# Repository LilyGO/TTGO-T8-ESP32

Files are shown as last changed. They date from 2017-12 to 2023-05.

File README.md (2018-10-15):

# TTGO-T8-ESP32

## T8 V1.7
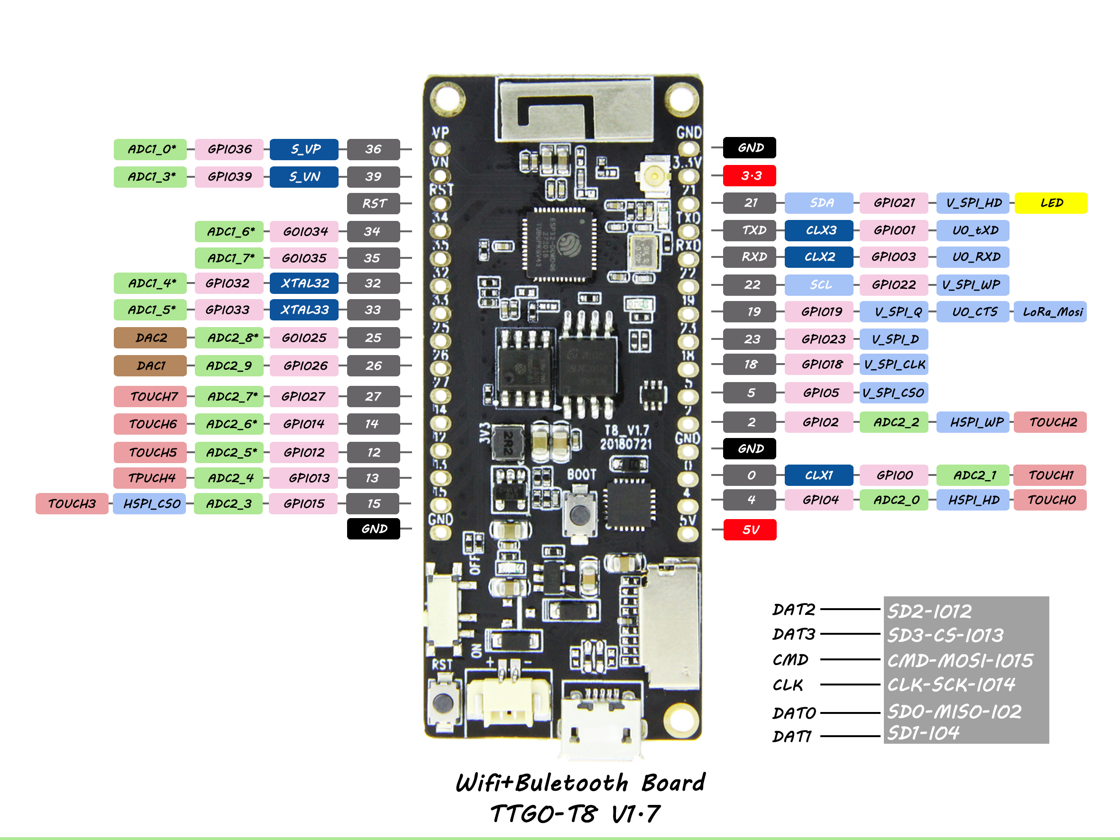
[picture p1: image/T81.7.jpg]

## T8 V1.3
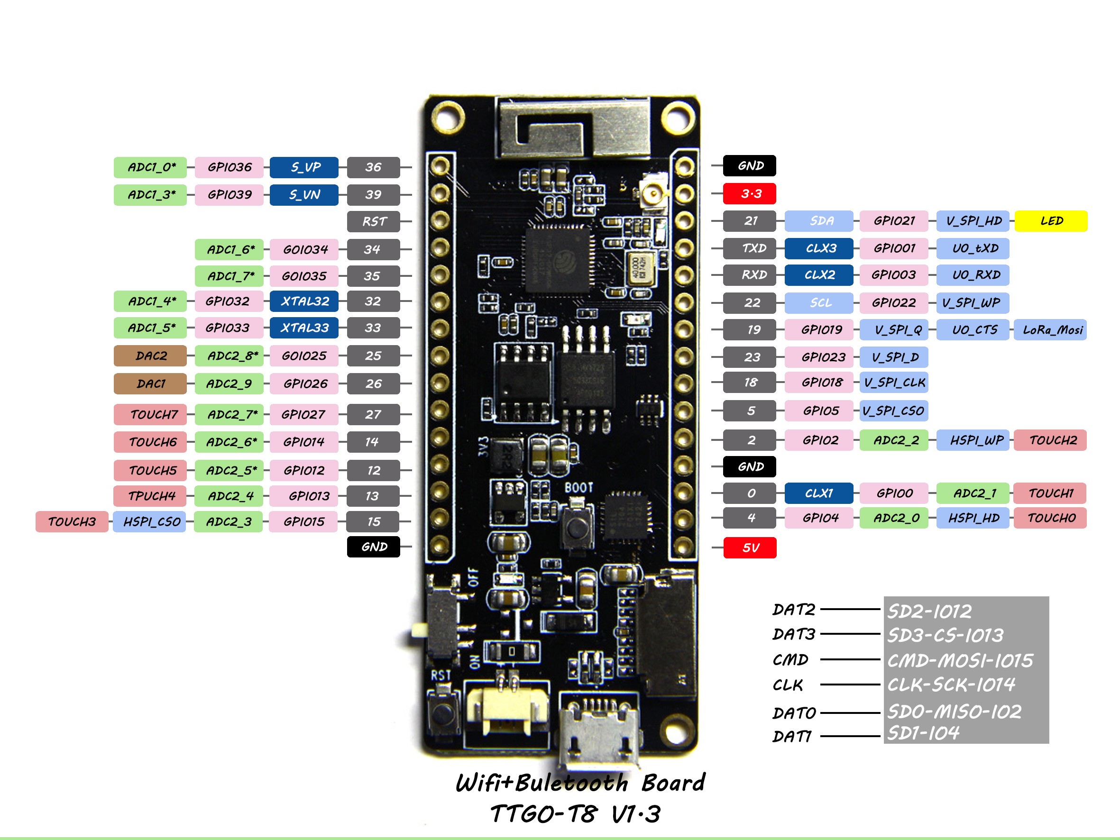
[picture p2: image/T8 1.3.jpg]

## T8 V1.1
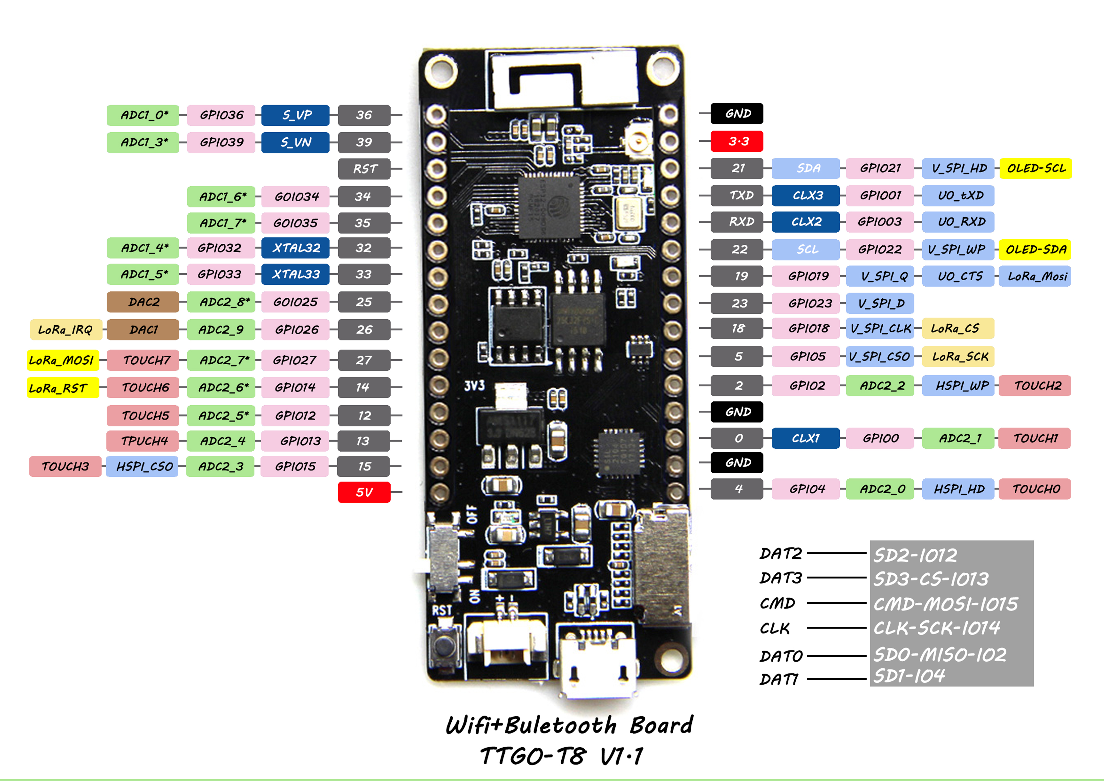
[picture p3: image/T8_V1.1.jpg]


esp32-i2s-sdcard-wav-player
Connect hardware like below:

[ESP32 IO33 – CS MICROSD]

[ESP32 IO14 – MOSI MICROSD]

[ESP32 IO12 – MISO MICROSD]

[ESP32 IO27 – SCK MICROSD]

[ESP32 IO26 – I2S codec BCK]

[ESP32 IO22 – I2S codec DATA]

[ESP32 IO25 – I2S codec LRCK]

[ESP32 GND – I2S codec GND]

[ESP32 GND – GND MICROSD]

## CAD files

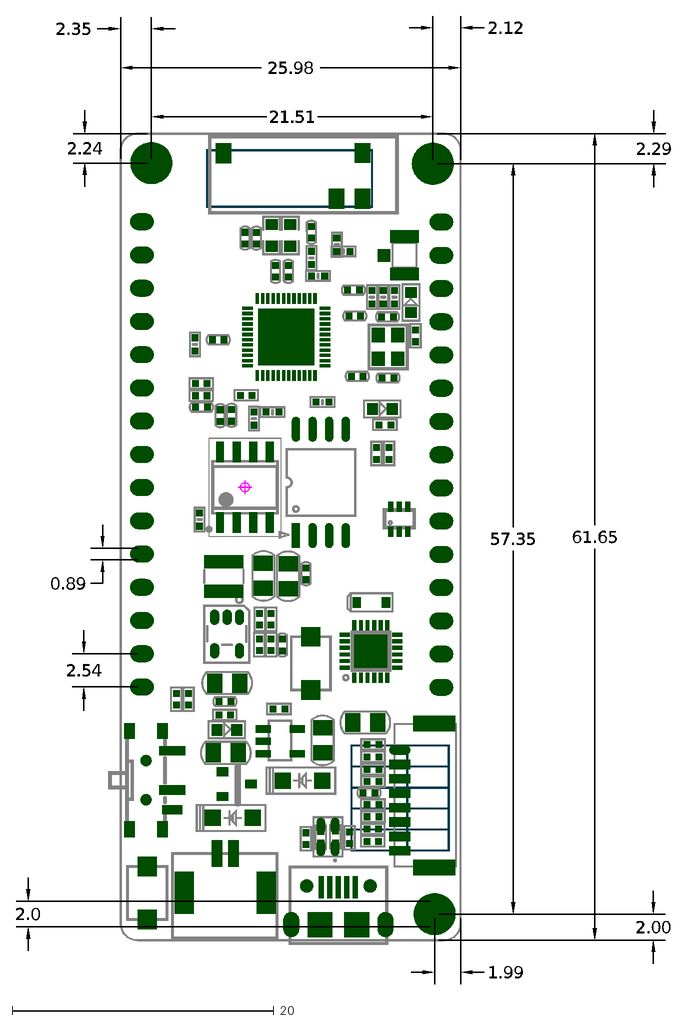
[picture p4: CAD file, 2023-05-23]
T8_V1.7.dxf
21.51
25.98
57.35
61.65
2.54
0.89
1.99
2.24
2.00
2.29
2.12
2.35
2.0

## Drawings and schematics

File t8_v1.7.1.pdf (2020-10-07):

5V-3.3V

## VBUS-VBAT-VIN

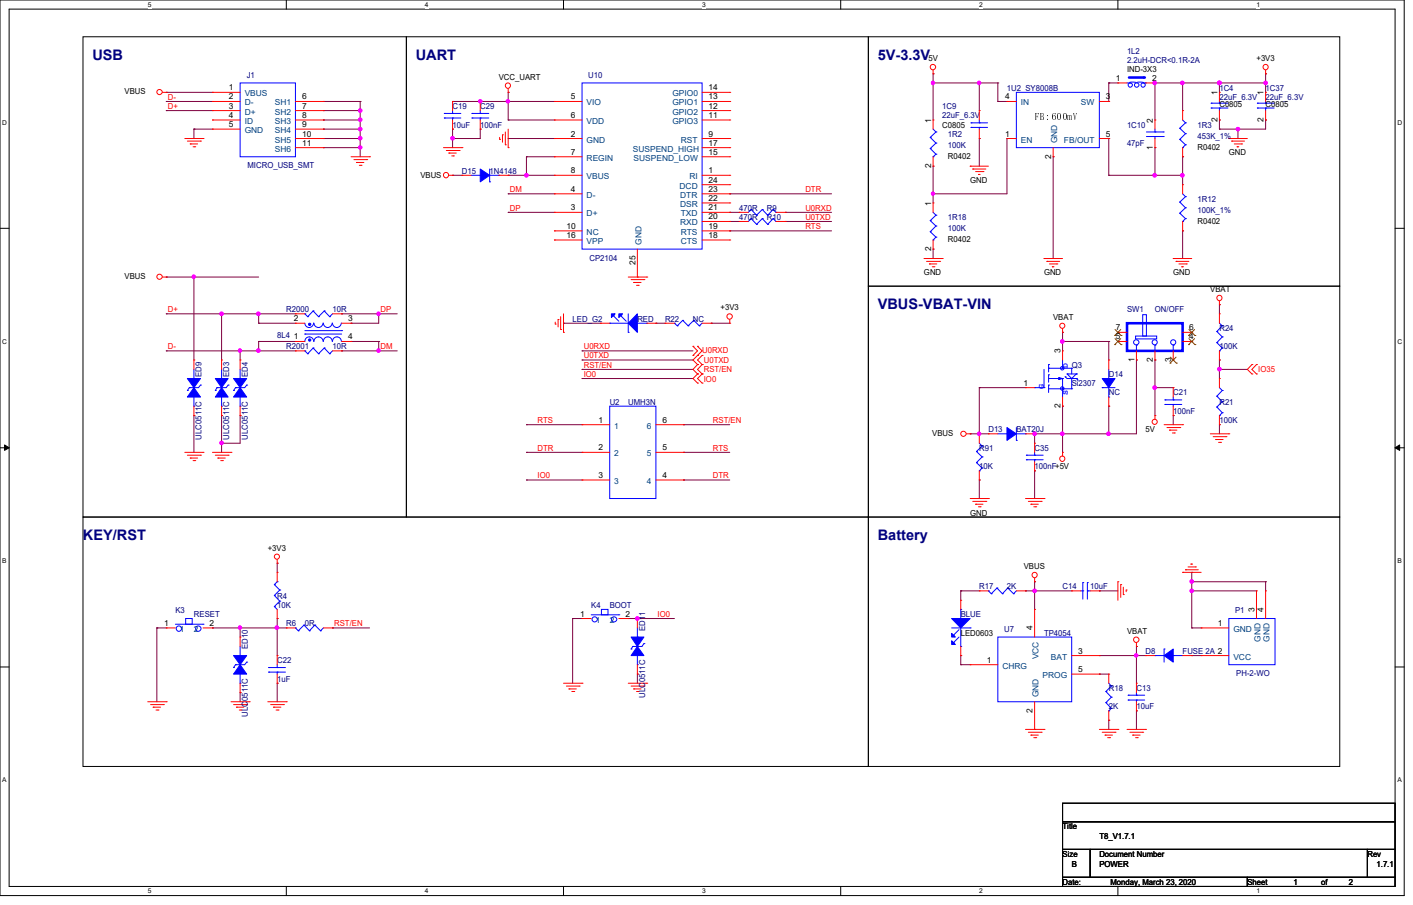
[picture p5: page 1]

## ESP32 Module:with 1.8V Flash & SRAM

The operating voltage for signals marked in blue is 1.8V.

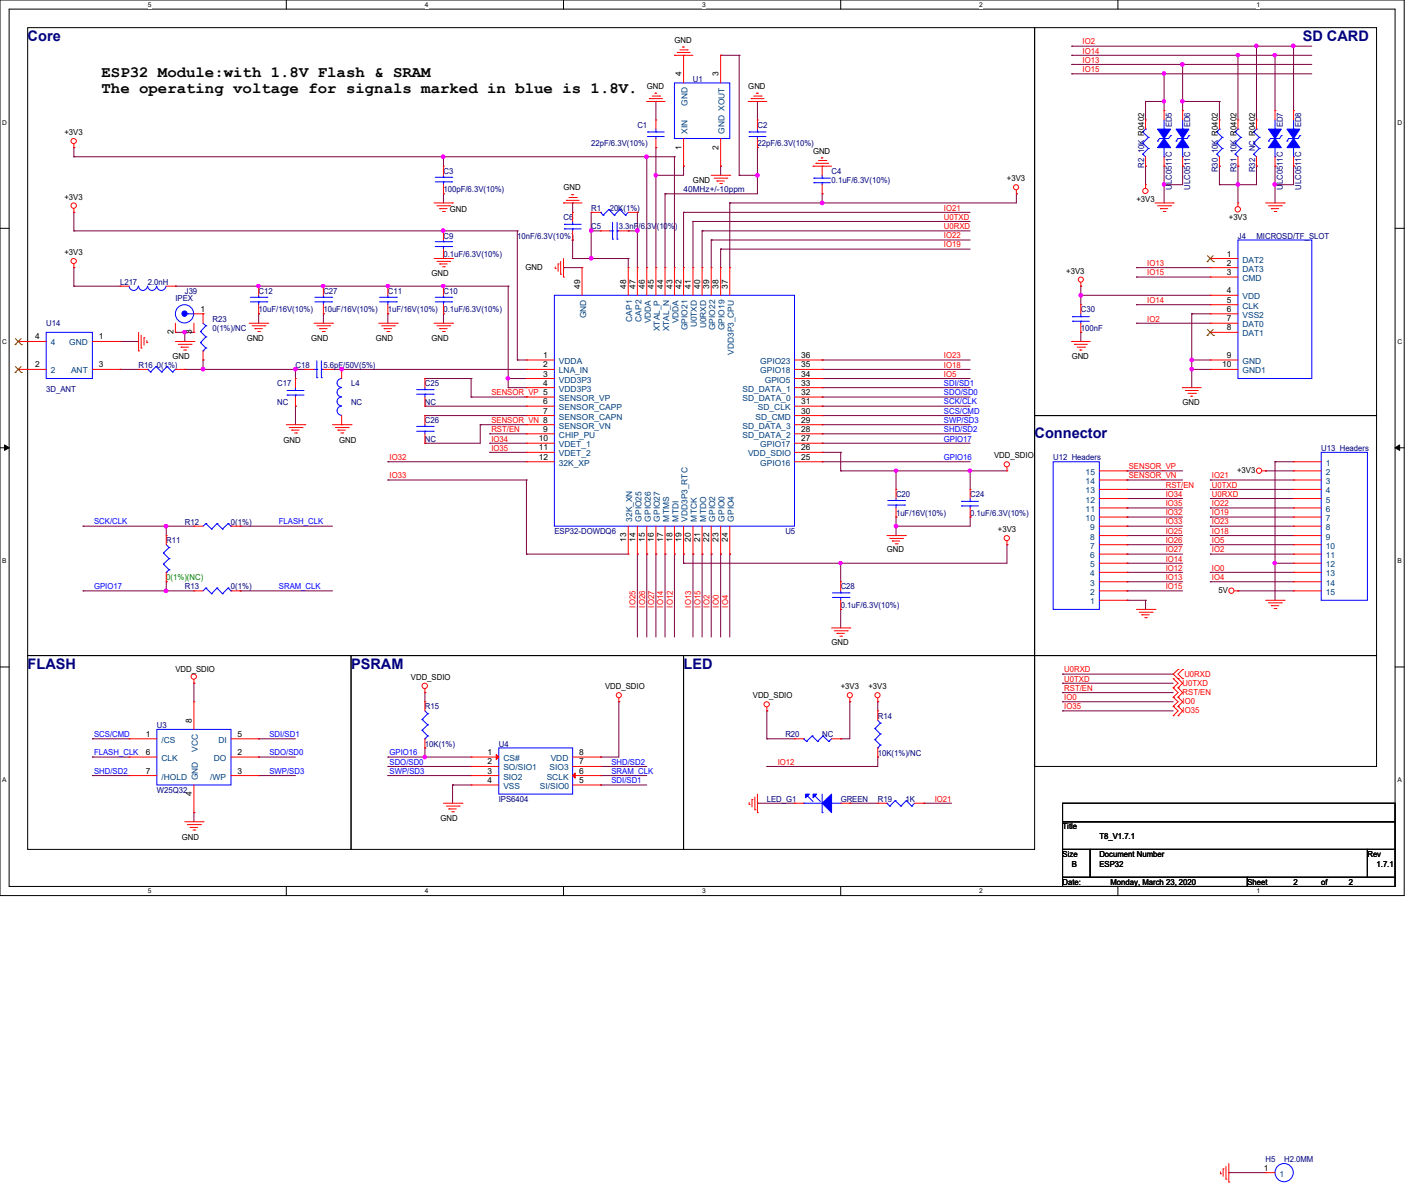
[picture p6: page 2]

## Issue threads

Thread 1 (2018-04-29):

On-board LEDs

elf55, 2018-04-29:
There are at least 3 on-board LEDs.  Is there documentation on how they are connected to GPIO pins?

LilyGO, 2018-05-24:
One is a power light, and the other is an LED foot controlled by the GPIO21 pin.

LilyGO, 2018-05-24:
If you need it, we can send you a T8 schematic

amirgon, 2018-05-24:
What would happen to the power light during deep-sleep? Would it still be on?

elf55, 2018-05-24:
A schematic would solve all questions, but knowing what the LEDs are connected to helps immediately.

pilnikov, 2018-08-14:
I need a schematic too
gpio 16, 17 where?

remedix, 2021-01-20:
Can you please explain how to turn off these LEDs ? There is one blinking LED and one constant on LED

pilnikov, 2021-01-21:
just unsolder

johndoesenior, 2021-02-04:
I need the schematic also.
I cant find TX2,RX2 in the pinout

Closed 2018-05-24.

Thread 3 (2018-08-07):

red/blue LEDs

carstenblt, 2018-08-07:
Hi there,
there are two LEDs on the board that I find are not connected to any GPIO. Am I just missing the right one? Any way to disable them via software?

Thanks in advance.

wieb18, 2019-02-03:
There is only 2 LEDs on this board, BLUE (power indicator) and GREEN (wifi indicator).
The GREEN LED can be controlled with GPIO21.
To turn off the BLUE LED, power the board through Lithium battery interface.

heeen, 2019-05-09:
the blue LED is connected to the battery charging controller, it goes off if the battery is not charging
the red LED is supposed to light when the board is powered, but it is not working for me, neither from USB, nor from a battery

heeen, 2019-05-09:
@LilyGO is it a known issue that the red led is not working?

PureBasic, 2019-05-10:
Wait, there is a red led ?
Doesn't work on my board neither then.

Le jeu. 9 mai 2019 à 19:30, Florian Hänel <notifications@github.com> a
écrit :

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

PureBasic, 2019-05-10:
Okay, just looked at it closely, the red led (LED_G2) is implanted but R22 (the 1k brake) is not.
If you want the red led to work you will need to solder the 0402 resistor. I believe they didn't implanted it to avoid draining batteries continuously. Better to blink LED_G1 (IO21) when needed

stanleyseow, 2020-05-19:
Where did you find the schematics for TTGO T18 V3.0 ???

PureBasic, 2020-05-19:
What is the T18?

patrickelectric, 2023-04-20:
My RED led is blinking like crazy, how do I control it ?

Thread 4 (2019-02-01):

SOLVED: TTGO T8 SD Card CS Pin???

wieb18, 2019-02-01:
I just bought TTGO T8 V1.1 board.

The board comes with installed "Hello World" and SD Card initialization sketch. It prints "Hello World" text and shows SD card files list in Serial Monitor when turn on for the first time. So, the SD card works fine.

**The problem is now I can't make SD card works anymore.**

[https://ae01.alicdn.com/kf/HTB1laFLXinrK1Rjy1Xcq6yeDVXaf.jpg](url)

Board picture says the SD card CS Pin is GPIO 13 but doesn't work. Already tried changing CS pin to GPIO 2, 4, 14, 15 but also doesn't work.

```
#include <SPI.h>
#include <SD.h>

File root;

void setup() {
  // Open serial communications and wait for port to open:
  Serial.begin(115200);
  while (!Serial) {
    ; // wait for serial port to connect. Needed for native USB port only
  }

  Serial.print("Initializing SD card...");

  if (!SD.begin(13)) {
    Serial.println("initialization failed!");
    while (1);
  }
  Serial.println("initialization done.");

  root = SD.open("/");

  printDirectory(root, 0);

  Serial.println("done!");
}

void loop() {
  // nothing happens after setup finishes.
}

void printDirectory(File dir, int numTabs) {
  while (true) {

    File entry =  dir.openNextFile();
    if (! entry) {
      // no more files
      break;
    }
    for (uint8_t i = 0; i < numTabs; i++) {
      Serial.print('\t');
    }
    Serial.print(entry.name());
    if (entry.isDirectory()) {
      Serial.println("/");
      printDirectory(entry, numTabs + 1);
    } else {
      // files have sizes, directories do not
      Serial.print("\t\t");
      Serial.println(entry.size(), DEC);
    }
    entry.close();
  }
}

```
Anybody knows how to enable TTGO T8 SD card?

Thanks.

wieb18, 2019-02-02:
Finally.... it works....  :

Change _SD.h_ library with _mySD.h_ library from [https://github.com/nhatuan84/esp32-micro-sdcard](https://github.com/nhatuan84/esp32-micro-sdcard).

```
#include <SPI.h>
#include <mySD.h>

File root;
const int chipSelect = 13;

void setup()
{
  Serial.begin(115200);
  Serial.print("Initializing SD card...");
  pinMode(SS, OUTPUT);

  //SDClass::begin(uint8_t csPin, int8_t mosi, int8_t miso, int8_t sck)
  if (!SD.begin(13, 15, 2, 14)) {
    Serial.println("initialization failed!");
    return;
  }

  Serial.println("initialization done.");

  root = SD.open("/");

  printDirectory(root, 0);

  Serial.println("done!");
}

void loop()
{
  // nothing happens after setup finishes.
}

void printDirectory(File dir, int numTabs) {
  // Begin at the start of the directory
  dir.rewindDirectory();

  while(true) {
     File entry =  dir.openNextFile();
     if (! entry) {
       // no more files
       //Serial.println("**nomorefiles**");
       break;
     }
     for (uint8_t i=0; i<numTabs; i++) {
       Serial.print('\t');   // we'll have a nice indentation
     }
     // Print the 8.3 name
     Serial.print(entry.name());
     // Recurse for directories, otherwise print the file size
     if (entry.isDirectory()) {
       Serial.println("/");
       printDirectory(entry, numTabs+1);
     } else {
       // files have sizes, directories do not
       Serial.print("\t\t");
       Serial.println(entry.size(), DEC);
     }
     entry.close();
   }
}
```

Conclusion, nothing wrong with SD Card GPIO print on the back of the board.

The root of this issue cause by SD.h library which unable to detect TTGO SD card because it used custom CS, MOSI, MISO, SCK sequence.

gandy92, 2022-08-07:
It also works with the standard SD library:
```
#include <SPI.h>
#include <SD.h>

#define SD_CS 13

void setup()
{
    SPI.begin(14, 2, 15, 13);
    Serial.begin(115200);
    SD.begin(SD_CS);
    if (!SD.begin(SD_CS)) {
        Serial.println("Card Mount Failed");
        return;
    }
    uint8_t cardType = SD.cardType();
    if (cardType == CARD_NONE) {
        Serial.println("No SD card attached");
        return;
    }
    Serial.println("Initializing SD card...");
    if (!SD.begin(SD_CS)) {
        Serial.println("ERROR - SD card initialization failed!");
        return;    // init failed
    }
}
```

Closed 2019-02-02.

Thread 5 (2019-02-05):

Schematic

rochba, 2019-02-05:
Hello,
I'm working with these cards and I have a lot of questions about battery management, leds connectivity, antenna …
Is it possible to have access to the schematic. That will solve my issue.
Thanks,
Best regards,

ThomasChr, 2019-05-07:
This is the shematic: https://github.com/LilyGO/TTGO-T8-ESP32/blob/master/Schematic.pdf

Maslenikoff73, 2021-01-30:
> This is the shematic: https://github.com/LilyGO/TTGO-T8-ESP32/blob/master/Schematic.pdf
link not work :(

ThomasChr, 2021-01-30:
Try this one: https://github.com/LilyGO/TTGO-T8-ESP32/raw/master/t8_v1.7.1.pdf

Maslenikoff73, 2021-02-03:
Thanks 👍

Cyb3r-N1nja, 2022-02-28:
Does anyone here have a working source code to display something to the Display because in my case it says written successfully and the screen remains black

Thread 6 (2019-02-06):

Which board should i use?

sync5, 2019-02-06:
I'm not sure which esp32 board from the Arduino IDE should I use for this ttgo-t8 1.3? Thanks.

knopserl, 2019-03-17:
same question here: TTGO T8 v1.7. it would be nice and required if a board definition is provided for Arduino Studio.
We always have o use another board like WEMOS LOLIN32 and do a lot of manual works to redefine and add the additional peripherals like the SD Cards etc.

m-menon, 2019-04-11:
> I'm not sure which esp32 board from the Arduino IDE should I use for this ttgo-t8 1.3? Thanks.

LOLIN D32 PRO seems to work for me. I had my board running only for a short while so I haven't tested it completely. The only thing I tested was a I2C OLED on pins 21/22 (SDA/SCL).

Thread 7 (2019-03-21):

microSD data pins

kaofishy, 2019-03-21:
The pinout for all versions of the board states that the microSD data pins are correctly connected to the SDMMC host interface on the ESP32, but in the schematics it shows DAT1-3 as disconnected and only DAT0 connected. On the board I have I can only make SDMMC work in 1-bit mode so it suggests to me the schematics is correct. Please confirm whether this is the case or not. Thanks.

tionebrr, 2020-07-22:
The sd slot is wired in SPI 1-bit mode.

venice1200, 2021-03-20:
I can confirm working 1-Bit SD-Bus-Mode and SPI Mode.
But I have to **SD_MMC.begin("/sdcard", true)** twice in my Arduino Sketch.
First **.begin** fails, second is OK.

koradeh, 2024-06-01:
`// pullup GPIO2 for SD_MMC mode, you need 1-15kOm resistor connected to GPIO2 and GPIO19 `
Or
`pinMode(2, INPUT_PULLUP);`

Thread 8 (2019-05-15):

Deepsleep only 3.5 mA

ThomasChr, 2019-05-15:
When I put the ESP32 in deepsleep I still have a power draw of ~3.5mA.
Can you explain why is that so, and can I do anything about it?

ThomasChr, 2019-05-17:
I‘ve desoldered the SIL2104 and now the power consumption is down to 3.1 mA, better, but far from the uA the ESP32 is capable of!

ThomasChr, 2019-05-20:
The problems seems to be that VDD_SDIO stays at 3.3V in deepsleep, so flash and psram do not get powered down.

ThomasChr, 2019-05-20:
Some news here:
1. VDD_SDIO does not go low when entering deepsleep. It seems that the Resistor R20 is placed on the board and pulling VDD_SDIO to 3.3V. Removing it helped and I lost one more mA (1.5 mA total in deepsleep)
2. I powered the board directly on the 3.3V rail, so the SYS8008B Voltage regulator was not involved and I'm down to 295 µA.

So still there are some 280 µA to catch. Anyone got an idea what I can try now?
Of course, everything is allowed, even experiments which will destroy the board, all to satisfy my curiosity!

ThomasChr, 2019-05-21:
After blowing the power IC completely from the board the power consumption is down to 100 µA - getting there! Any hints what should be blown off next? Some pullup resistors maybe?

PureBasic, 2019-05-21:
Wow, that was a very leaky regulator...
You could just check the voltage across all the remaining resistors. R1, R4, R11, R12, R13, R14 and R19. Also there is 1R3 and 1R12 voltage divider close to the SYS8008B if still connected draining a bit for sure.
It may also be a leaky cap somewhere, which is harder to find.

ThomasChr, 2019-05-21:
Hi PureBasic, thank you very much for your answer!

Is there anywhere a Layout of the board? The resistors are not marked on the PCB which makes it very hard to find the right one!

PureBasic, 2019-05-22:
Arf you will have to follow the schematic, count the pins and so on... There is no TOPCOMP sheet from what I gathered.
1R3 and 1R12 should be close the SYS8008, they are draining 6uA (553k @ 3.3v).

How much exceding current do you still have to find ? You are feeding power directly to the 3v3 net or VBat ?

ThomasChr, 2019-05-22:
Hello PureBasic,

I just blowed some resistors of the board and this is the outcome:
1. Without voltage regulator (providing 3.3V directly on the rail): 100 µA
2. Without the Voltage Divider from the Power IC: 90 µA
3. Without the pullups for the SD Card IO Lines: 5 µA

So I think I'm pretty much done :-)

PureBasic, 2019-05-22:
Nice !
It's weird that the SD pullups are draining that much current, because they are marked as NC on the schematic, so maybe you actually removed the ESD protections 😆.
Did you checked the state of the IOs of the ESP32 when it goes in hibernation ? They should all be put in "INPUT" mode with no internal pullups or pulldowns, so virtually connected to nothing inside the ESP32.

Civilduino, 2019-07-22:
And NC means Not Connected?

PureBasic, 2019-07-22:
Yes. But check on the board, you never know...

hpsaturn, 2020-04-14:
Nice thread, guys maybe you know what is the better TTGO board "out the box" with this improvements? thats is, what board has the better performance for hibernation without any hack?
For example TTGO-T-Writsband in my tests reached ~3 days only on suspend mode (not bad because the battery is very tiny), maybe the TTGO T-Display will be? (I'm waiting for a one board for starting tests)

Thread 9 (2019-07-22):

External antenna TTGO T8

Civilduino, 2019-07-22:
I got the TTGO T8 V1.7 20180721 and I will like to use the external antenna connector. Is it just to plug the antenna?

I tried that I don't think it is working. Do I need to solder some resistor, cut a trace? add a jumper?

Without the antenna the board is useless for my application.

Thank you for clarification and improving the documentation. Some pictures of what to do should be good.

KuhlTime, 2020-06-27:
I am having the same question. Looking at the schematic I would assume that you have to desolder R16 and bridge R23 (or use the desoldered 0Ω resistor). It would be nice to get some clarification on this though.

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

vaughnlfisher, 2021-03-26:
Did you ever get an answer to this

LiveRock, 2021-07-02:
Any answer to this? I bridge R23 with a wire (not resistor) and the performance because much much worse even with an external antenna...

KuhlTime, 2021-07-04:
Sadly I did not get an answer. My performance decreased as well when I tried that.

KuhlTime, 2021-07-04:
Maybe good to point out that there is another question regarding the IPEX antenna: https://github.com/LilyGO/TTGO-T8-ESP32/issues/20

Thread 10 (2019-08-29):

TTGO T8 V1.7 cannot be powered on from the battery

dukeduck1984, 2019-08-29:
Hi,

I recently bought 2 TTGO T8 V1.7 boards, neither can be powered on from a 18650 battery (fully charged, voltage measured 4.3V).  I also have a T8 V1.3 which works properly with the very same battery.

Any idea what can go wrong?

Thanks.

mattsmithuk, 2025-01-18:
Can I ask what the issue was? I am having a similar issue

Closed 2019-09-06.

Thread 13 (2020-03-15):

Battery measurement

eried, 2020-03-15:
Hi!

I just wanted to add that it would be useful to have the following info in the repo:

1) PIN 35 measures the VBAT (or USB) with a resistor divider bundled in the board.

```
    #define PIN_VBAT 35
    int v = analogRead(PIN_VBAT); // This returns the battery level
```

2) VCC does not provide any power if we use the battery (I do not know why, but it would be useful to change this in the pcb for next revision and provide USB/VBAT)

paolovr70, 2020-03-26:
Eried I have T8 1.7.1 board. Analog read finds a value in PIN35 around 2430. This level is present both with BATTERY connected and also with NO BATTERY. Are you sure that it correspond to V.bat?

eried, 2020-03-26:
Yes, in that case is USB voltage

paolovr70, 2020-03-27:
But what is the scale of 0-4095.measurement? Because lithium battery is 3.0-4.2v. Board and pins volt are maximum 3.3v and 0-4095 usually are for 0-3.3v. How.did you manage that?

eried, 2020-03-27:
Well, I didnt exactly needed the voltage value, just the reference (because the analogRead changes for every input responding to VBAT, so the values are all different if you are on battery power vs USB)

So what I did is to map the range:
https://github.com/eried/pidflight-lap-firmware/blob/master/pidflight_lap/rx5808.ino#L37

For a simple mapping I would use:

    #define PIN_VBAT 35
    double v = analogRead(PIN_VBAT)  / 4096 / 2 / 4.2 ; // This returns the voltage (max range / voltage divider / max battery voltage )
    // voltage divider = in the PCB of the T8 you can see there is 2 equal resistors, hence 50% division
    // max battery voltage = this is the output of the lipo charging circuitry before it gets to the 3.3 regulator... this circuit is before the ON/OFFswitch)

For a more accurate reading, I would calibrate a mapping with few known voltages and an polinomial interpolation in excel.

eried, 2020-03-27:
Also, consider that while reading the serial monitor via USB you will always get the same VBAT. Create a sketch with a simple bluetooth serial and try with different batteries.

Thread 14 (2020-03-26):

LEDS on TTGO ESP32 T8 1.7.1

paolovr70, 2020-03-26:
Dear All,
where can I find a pinout of the board? (on the site producer there is no schematic).
There are 3 leds on board. One is for battery, but the other two?
Are there problems if I need to use I2C and one of the leds is connected to 21/22 pins (which are the hardware I2C pins)?
Thanks.
paolo

tionebrr, 2020-07-22:
I Paolo.
- According to the schematic, blue is for battery charge, red is the 3v3 power, and green is wired to IO21.
- Schematic is in this repository, but the version changes are not pushed here. The pinout is the same as other official ESP32 modules.
- You can use any pin as I²C with the ESP32. GPIOs are actually very flexible. Refer to the ESP32 datasheet.

There is not a lot of help or information about this specific module (the T8) because there is nothing special about it really. It is wired like most other ESP32 modules and thus can be used like any other module. Only difference is the SDCard slot which is actually wired in SPI mode like shown on the schematic and not like advertised.

hasaranga, 2021-01-21:
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

Can it run in 1bit mode? Because I have the same board but the first call to **SD_MMC.begin("/sdcard", true)** always fail. Second call works. Tried with a different SD card and reduced the cpu freq but the same results.

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

tionebrr, 2021-01-22:
I'm using the ESP-IDF and thus don't know anything about the specifics of the arduino implementation.
Remember, the SDCard is wired as an SPI device, so it is one bit. There might be a way to tell SD_MMC to initialize as an SPI SD.

dizcza, 2021-09-03:
@tionebrr could you please clarify this

> Remember, the SDCard is wired as an SPI device, so it is one bit

aren't you trying to say that an SD card will work only in 1-bit width mode for this board while using the SD-MMC driver?

tionebrr, 2021-09-03:
@dizcza Good question.
The SDCard socket is not wired on SDMMC pins. So you can't have a 1-bit SDMMC.
I used the [SDSPI Host Driver](https://docs.espressif.com/projects/esp-idf/en/latest/esp32/api-reference/peripherals/sdspi_host.html) to make it work.

tionebrr, 2021-09-03:
@dizcza You're right, sorry for the confusion. I re-checked the docs and it should work in SDMMC 1-bit mode. I edited my previous comment.

dizcza, 2021-09-03:
@tionebrr thank you for the clarification. It did help because I thought I was doing something wrong by not being able to mount an SD card with the 4-bit operation mode.

BTW, shouldn't this issue be closed? It has been answered fairly in the first comment. The author perhaps was wondering whether the LED will be blinking if IO21 pin is used as SDA with some I2C-connected device. In either case, you can't use it as LED with active I2C communication going through this pin.

Let me also answer another question posted here to quantify it's fully resolved.
@hasaranga you had the following problem:
> ... I have the same board but the first call to SD_MMC.begin("/sdcard", true) always fail. Second call works.

It's because a pull-up resistor is missing on D0 line (as in many other variants of an ESP32 board). You can do either a hardware fix (pulling up a 10 kOhm resistor to pin "2") or a software fix. The software fix is to call `pinMode(2, INPUT_PULLUP);` prior to initializing the SD card. Below is a working example of using SDMMC driver with TTGO T8 in Arduino IDE with the latest esp32 library installed (v1.0.6; I've not checked v2.0.0 yet).

<details>
    <summary>An example of using SDMMC driver with TTGO T8 in Arduino IDE</summary>

```c
/*
 * Connect the SD card to the following pins:
 *
 * SD Card | ESP32
 *    D2       12
 *    D3       13
 *    CMD      15
 *    VSS      GND
 *    VDD      3.3V
 *    CLK      14
 *    VSS      GND
 *    D0       2  (add 1K pull up after flashing)
 *    D1       4
 */

#include "FS.h"
#include "SD_MMC.h"

void listDir(fs::FS &fs, const char * dirname, uint8_t levels){
    Serial.printf("Listing directory: %s\n", dirname);

    File root = fs.open(dirname);
    if(!root){
        Serial.println("Failed to open directory");
        return;
    }
    if(!root.isDirectory()){
        Serial.println("Not a directory");
        return;
    }

    File file = root.openNextFile();
    while(file){
        if(file.isDirectory()){
            Serial.print("  DIR : ");
            Serial.println(file.name());
            if(levels){
                listDir(fs, file.name(), levels -1);
            }
        } else {
            Serial.print("  FILE: ");
            Serial.print(file.name());
            Serial.print("  SIZE: ");
            Serial.println(file.size());
        }
        file = root.openNextFile();
    }
}

void createDir(fs::FS &fs, const char * path){
    Serial.printf("Creating Dir: %s\n", path);
    if(fs.mkdir(path)){
        Serial.println("Dir created");
    } else {
        Serial.println("mkdir failed");
    }
}

void removeDir(fs::FS &fs, const char * path){
    Serial.printf("Removing Dir: %s\n", path);
    if(fs.rmdir(path)){
        Serial.println("Dir removed");
    } else {
        Serial.println("rmdir failed");
    }
}

void readFile(fs::FS &fs, const char * path){
    Serial.printf("Reading file: %s\n", path);

    File file = fs.open(path);
    if(!file){
        Serial.println("Failed to open file for reading");
        return;
    }

    Serial.print("Read from file: ");
    while(file.available()){
        Serial.write(file.read());
    }
}

void writeFile(fs::FS &fs, const char * path, const char * message){
    Serial.printf("Writing file: %s\n", path);

    File file = fs.open(path, FILE_WRITE);
    if(!file){
        Serial.println("Failed to open file for writing");
        return;
    }
    if(file.print(message)){
        Serial.println("File written");
    } else {
        Serial.println("Write failed");
    }
}

void appendFile(fs::FS &fs, const char * path, const char * message){
    Serial.printf("Appending to file: %s\n", path);

    File file = fs.open(path, FILE_APPEND);
    if(!file){
        Serial.println("Failed to open file for appending");
        return;
    }
    if(file.print(message)){
        Serial.println("Message appended");
    } else {
        Serial.println("Append failed");
    }
}

void renameFile(fs::FS &fs, const char * path1, const char * path2){
    Serial.printf("Renaming file %s to %s\n", path1, path2);
    if (fs.rename(path1, path2)) {
        Serial.println("File renamed");
    } else {
        Serial.println("Rename failed");
    }
}

void deleteFile(fs::FS &fs, const char * path){
    Serial.printf("Deleting file: %s\n", path);
    if(fs.remove(path)){
        Serial.println("File deleted");
    } else {
        Serial.println("Delete failed");
    }
}

void testFileIO(fs::FS &fs, const char * path){
    File file = fs.open(path);
    static uint8_t buf[512];
    size_t len = 0;
    uint32_t start = millis();
    uint32_t end = start;
    if(file){
        len = file.size();
        size_t flen = len;
        start = millis();
        while(len){
            size_t toRead = len;
            if(toRead > 512){
                toRead = 512;
            }
            file.read(buf, toRead);
            len -= toRead;
        }
        end = millis() - start;
        Serial.printf("%u bytes read for %u ms\n", flen, end);
        file.close();
    } else {
        Serial.println("Failed to open file for reading");
    }

    file = fs.open(path, FILE_WRITE);
    if(!file){
        Serial.println("Failed to open file for writing");
        return;
    }

    size_t i;
    start = millis();
    for(i=0; i<2048; i++){
        file.write(buf, 512);
    }
    end = millis() - start;
    Serial.printf("%u bytes written for %u ms\n", 2048 * 512, end);
    file.close();
}

void setup(){
    Serial.begin(115200);
    delay(1000);
    pinMode(2, INPUT_PULLUP);
    if(!SD_MMC.begin("/sdcard", true, false)){
        Serial.println("Card Mount Failed");
        return;
    }
    uint8_t cardType = SD_MMC.cardType();

    if(cardType == CARD_NONE){
        Serial.println("No SD_MMC card attached");
        return;
    }

    Serial.print("SD_MMC Card Type: ");
    if(cardType == CARD_MMC){
        Serial.println("MMC");
    } else if(cardType == CARD_SD){
        Serial.println("SDSC");
    } else if(cardType == CARD_SDHC){
        Serial.println("SDHC");
    } else {
        Serial.println("UNKNOWN");
    }

    uint64_t cardSize = SD_MMC.cardSize() / (1024 * 1024);
    Serial.printf("SD_MMC Card Size: %lluMB\n", cardSize);

    listDir(SD_MMC, "/", 0);
    createDir(SD_MMC, "/mydir");
    listDir(SD_MMC, "/", 0);
    removeDir(SD_MMC, "/mydir");
    listDir(SD_MMC, "/", 2);
    writeFile(SD_MMC, "/hello.txt", "Hello ");
    appendFile(SD_MMC, "/hello.txt", "World!\n");
    readFile(SD_MMC, "/hello.txt");
    deleteFile(SD_MMC, "/foo.txt");
    renameFile(SD_MMC, "/hello.txt", "/foo.txt");
    readFile(SD_MMC, "/foo.txt");
    testFileIO(SD_MMC, "/test.txt");
    Serial.printf("Total space: %lluMB\n", SD_MMC.totalBytes() / (1024 * 1024));
    Serial.printf("Used space: %lluMB\n", SD_MMC.usedBytes() / (1024 * 1024));
}

void loop(){

}
```

</details>

dizcza, 2021-09-04:
@tionebrr
could you also clarify
> You can use any pin as I²C with the ESP32

Clearly, we cannot use *any* GPIO pin as I2C, can we? There are only two I2C according to the seller information. One is at 21 & 22 pins. Where is the other? (I'd like to keep pin 21 for LED.)
Thank you.

tionebrr, 2021-09-04:
@dizcza Not really any indeed. You can't use a "input only" pin for SDA for example.
There are two I2C peripherals in the ESP32 but they are behind a GPIO Mux. You can route most ESP32 internal peripherals to any pins. The GPIO Mux might introduce timing issues with high speed stuff (because it's clocked by the APB at 80MHz), so some peripherals are better used with their default pins. I2C is obviously tolerant enough.
You can check the list in the [datasheet](https://www.espressif.com/sites/default/files/documentation/esp32_datasheet_en.pdf) page 37.

Also I agree that this issue should be closed. But the LilyGo folks does not seem to be monitoring this repository at all.

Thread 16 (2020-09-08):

Dimensions

Lithimlin, 2020-09-08:
Is there a possibility to get the dimensions of this board? This includes the distance between the bin headers, the drilled holes, the length and width of the board, the position of the SD-Card slot and USB-port.

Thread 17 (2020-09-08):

Discharge battery

ReliableBob, 2020-09-08:
Hello to all.
I have a T8 V1.7 board.
I connected an 18650 lithium battery to the board. After turning off the main power, the board switched to battery power. After working for about eight hours, the power turned off. I thought it was ok, but I measured the voltage on the battery. It was 1.86 volts.
This is very small. The battery may be damaged ...
I studied the circuit and did not see the battery discharge control elements ... This is very bad ...
Correct if I'm wrong, but it turns out that there is no battery discharge control in such an excellent circuit? How can it be?

tionebrr, 2020-09-08:
Yeah it is not such an excellent circuit. This is a cost optimized development board. Can't make coffee. ;)

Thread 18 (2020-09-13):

schematic for TTGO-T8-ESP32 v1.8

javarobotic, 2020-09-13:
Hi,

I got the new esp32 T8 v1.8 below:
https://www.aliexpress.com/item/32879370278.html

Wondering if there is really a TTGO-T8-ESP32 v1.8? I cannot find any information about correct pinout and schematic.
Is there any accurate pinout diagram or schematic available? The pinout mentioned in the store is wrong.

fritzlaszlo, 2022-02-22:
Hi, I am having the same problem. @LilyGO, if you could send me a schematic, that would help a lot. Thank you!

John-Tito, 2022-03-07:
> Hi, I am having the same problem. @LilyGO, if you could send me a schematic, that would help a lot. Thank you!

这是你正在找的东西吗？
is this what u are looking for？
https://github.com/Xinyuan-LilyGO/LILYGO-T8

它就在商品介绍页面中。
It is just in the product introduction page
https://www.aliexpress.com/item/32879370278.html

HankLloydRight, 2022-07-06:
Thank you for the schematic.
If I am supplying +5v power to the board not via the micro-USB jack, do I send +5v to the VIN(VBUS) pin #16 or the +5V pin #15?

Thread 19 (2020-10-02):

Unpopulated C25 on SENSOR_VP(SENSOR_CAPP), C26 on SENSOR_VN(SENSOR_CAPN)

d51r3verse, 2020-10-02:
V1.7.1 Unpopulated SMD
* C25(GPIO36-GPIO27), C26(GPIO39-GPIO38)
* R22 on RED(Power) LED

I wish to know how about yours one?

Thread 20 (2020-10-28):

Hows to use IPEX antenna

pidou46, 2020-10-28:
Please, could you give instructions how to use IPEX antenna instead of 3D antenna built in ?

dgoadby, 2020-10-29:
The circuit diagram shows two 0 ohm resistors (aka links). To use an external antenna via the Apex socket you need to remove R11 and add a link to R10. Note: not all of my LilyGO's have the Apex socket fitted. If the Apex socket is not fitted then the pads are usually there to add one. Here is a useful link for a different board but the idea is the same: [Using the Apex antenna socket](https://randomnerdtutorials.com/esp32-cam-connect-external-antenna/.)

pidou46, 2020-10-30:
Thank you for your answer.

I have two board with different revision.
For one of it it's obvious I see the circuit make a Y and it's easy  two understand wish resistor need to be removed and where to make the link.

But for the second one, there is a bunch of 4 resistors and I'm unable to identify wish one to remove and where to solder!
I try to make a picture but failed to get a nice one.

I suggest for the next release, that you add it on the pin layout to avoid recurrent questions about it.

pidou46, 2020-10-30:
My board is T8 V1.1
Here is what I think I have to do:
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
Are you agree ?

visicon-masc, 2021-04-06:
> I will research this some more as I too need to use an external antenna. For now I hope that I have been of some help.

Any news on this topic? Has anyone any expirience in using IPEX antenna without populating C17 and L4?
Has anyone gained information about values for C17 and L4 for correct matching? (Talking about v1.7)

LiveRock, 2021-07-05:
I asked my supplier and he said only a resistor bridge is needed. I tried but it does not work. I am asking him to double check with the manufacturer. Thanks

heol-files, 2021-08-12:
Any news on this?
After looking at my boards the above suggestion that I have to add extra capacitors/Inductors after moving the link R16 -> R23 seems to be the way to go to me.

heol-files, 2021-08-12:
@LiveRock Have not tried it yet, missing components. But I have IPEX connectors so I will try mount one on a TTGO T7_V1.4 instead and move the link R15 -> R14 to see if that works.
Last picture in this thread:
https://github.com/LilyGO/TTGO-T7-Demo/issues/3

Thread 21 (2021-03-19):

Removing the onboard 3.3 V regulator

LiveRock, 2021-03-19:
1. How much current can the onboard 3.3V regulator supply?
2. Where is it located and can I remove to be replaced with an external 3.3 regulator?

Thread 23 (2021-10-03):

TTGO v1.7.1 - pin 3v3 actually 3v8

RalphBacon, 2021-10-03:
The 3v3 pin on my TTGO v1.7.1 is measured as 3v854 on two multimeters. This voltage actually goes to the ESP32 chip, so I'm wondering two things:

1. Why is the voltage so high?
2. How does the ESP32 D0WDQ6 chip survive?

The voltage regulator on the board has a mark **LPS A18A2** on top, which I can't find on the internet. According to the TTGO schematic this should be a **SY8008B** LDO.

Do I have a fake TTGO or is something else going on? Specifically, should I replace that voltage regulator (SOT223-5 format) with a known device that gives out 3v3?

The board is working just fine, with WiFi and ESP32-NOW all enabled, but I am wary about using this device "in the field".

koradeh, 2024-06-01:
Please Check your GND is really **GND** ?!

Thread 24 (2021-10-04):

Failed to init external RAM!

Olofforsberg, 2021-10-04:
Hi

I am trying to use the esp-camera example with this board and have connected my camera on the pins. My problem is I need the PSRAM for this example and I do not manage to initialize the external 8Mbit Ram. Any suggestions?

`Rebooting...
ets Jun  8 2016 00:22:57

rst:0xc (SW_CPU_RESET),boot:0x13 (SPI_FAST_FLASH_BOOT)
configsip: 0, SPIWP:0xee
clk_drv:0x00,q_drv:0x00,d_drv:0x00,cs0_drv:0x00,hd_drv:0x00,wp_drv:0x00
mode:DIO, clock div:1
load:0x3fff0030,len:7308
ho 0 tail 12 room 4
load:0x40078000,len:14988
load:0x40080400,len:4404
0x40080400: _init at ??:?

entry 0x40080694
I (28) boot: ESP-IDF v4.3-dirty 2nd stage bootloader
I (29) boot: compile time 17:08:20
I (29) boot: chip revision: 1
I (32) boot_comm: chip revision: 1, min. bootloader chip revision: 0
I (48) qio_mode: Enabling QIO for flash chip WinBond
I (48) boot.esp32: SPI Speed      : 80MHz
I (49) boot.esp32: SPI Mode       : QIO
I (54) boot.esp32: SPI Flash Size : 4MB
I (59) boot: Enabling RNG early entropy source...
I (64) boot: Partition Table:
I (67) boot: ## Label            Usage          Type ST Offset   Length
I (75) boot:  0 nvs              WiFi data        01 02 00011000 00006000
I (82) boot:  1 phy_init         RF data          01 01 00017000 00001000
I (90) boot:  2 factory          factory app      00 00 00020000 00100000
I (97) boot: End of partition table
I (101) boot_comm: chip revision: 1, min. application chip revision: 0
I (109) esp_image: segment 0: paddr=00020020 vaddr=3f400020 size=0e6bch ( 59068) map
I (134) esp_image: segment 1: paddr=0002e6e4 vaddr=3ffb0000 size=01934h (  6452) load
I (137) esp_image: segment 2: paddr=00030020 vaddr=400d0020 size=1de50h (122448) map
I (176) esp_image: segment 3: paddr=0004de78 vaddr=3ffb1934 size=010d4h (  4308) load
I (177) esp_image: segment 4: paddr=0004ef54 vaddr=40080000 size=0e618h ( 58904) load
I (202) esp_image: segment 5: paddr=0005d574 vaddr=50000000 size=00010h (    16) load
I (210) boot: Loaded app from partition at offset 0x20000
I (210) boot: Disabling RNG early entropy source...
I (222) psram: This chip is ESP32-D0WD
E (222) psram: PSRAM ID read error: 0xffffffff
E (222) cpu_start: Failed to init external RAM!`

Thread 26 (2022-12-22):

VCC_UART

TadyTheFish, 2022-12-22:
Hello
Looking at the schematic I saw the UART chips VCC pin is marked as UART_VCC.
Where is this pin connected? is ther a jumper that you can disable the UART chip for low power mode?

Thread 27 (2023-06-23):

ESP32 TTGO T8 external anttenna connection

ASLANOGLUB, 2023-06-23:
Where are the resisostors that I am supposed to disconncet/reconnect
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

ASLANOGLUB, 2023-06-23:
Further to my inquiry, documentaion shows diffrenet resistors around the ipex pin. But ny card seesm to be blank

Andy-45, 2025-01-05:
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

remove (1) and solder it to (2)

https://www.youtube.com/watch?v=ckPu18lrBkE

btw: I would not do this without good solder experience

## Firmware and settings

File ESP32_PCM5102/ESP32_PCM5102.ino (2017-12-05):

#include <mySD.h>
#include "driver/i2s.h"
#include "freertos/queue.h"

#define CCCC(c1, c2, c3, c4)    ((c4 << 24) | (c3 << 16) | (c2 << 8) | c1)

/* These are data structures to process wav file */
typedef enum headerState_e {
    HEADER_RIFF, HEADER_FMT, HEADER_DATA, DATA
} headerState_t;

typedef struct wavRiff_s {
    uint32_t chunkID;
    uint32_t chunkSize;
    uint32_t format;
} wavRiff_t;

typedef struct wavProperties_s {
    uint32_t chunkID;
    uint32_t chunkSize;
    uint16_t audioFormat;
    uint16_t numChannels;
    uint32_t sampleRate;
    uint32_t byteRate;
    uint16_t blockAlign;
    uint16_t bitsPerSample;
} wavProperties_t;
/* variables hold file, state of process wav file and wav file properties */    
File root;
headerState_t state = HEADER_RIFF;
wavProperties_t wavProps;

//i2s configuration 
int i2s_num = 0; // i2s port number
i2s_config_t i2s_config = {
     .mode = (i2s_mode_t)(I2S_MODE_MASTER | I2S_MODE_TX),
     .sample_rate = 36000,
     .bits_per_sample = I2S_BITS_PER_SAMPLE_16BIT,
     .channel_format = I2S_CHANNEL_FMT_RIGHT_LEFT,
     .communication_format = (i2s_comm_format_t)(I2S_COMM_FORMAT_I2S | I2S_COMM_FORMAT_I2S_MSB),
     .intr_alloc_flags = ESP_INTR_FLAG_LEVEL1, // high interrupt priority
     .dma_buf_count = 8,
     .dma_buf_len = 64   //Interrupt level 1
    };
    
i2s_pin_config_t pin_config = {
    .bck_io_num = 26, //this is BCK pin
    .ws_io_num = 25, // this is LRCK pin
    .data_out_num = 22, // this is DATA output pin
    .data_in_num = -1   //Not used
};
//
void debug(uint8_t *buf, int len){
  for(int i=0;i<len;i++){
    Serial.print(buf[i], HEX);
    Serial.print("\t");
  }
  Serial.println();
}
/* write sample data to I2S */
int i2s_write_sample_nb(uint32_t sample){
  return i2s_write_bytes((i2s_port_t)i2s_num, (const char *)&sample, sizeof(uint32_t), 100);
}
/* read 4 bytes of data from wav file */
int read4bytes(File file, uint32_t *chunkId){
  int n = file.read((uint8_t *)chunkId, sizeof(uint32_t));
  return n;
}

/* these are function to process wav file */
int readRiff(File file, wavRiff_t *wavRiff){
  int n = file.read((uint8_t *)wavRiff, sizeof(wavRiff_t));
  return n;
}
int readProps(File file, wavProperties_t *wavProps){
  int n = file.read((uint8_t *)wavProps, sizeof(wavProperties_t));
  return n;
}

void setup()
{
  Serial.begin(115200);
  Serial.print("Initializing SD card...");
  if (!SD.begin(33, 14, 12, 27)) {
    Serial.println("initialization failed!");
    return;
  }
  Serial.println("initialization done.");
  delay(1000);
  /* open wav file and process it */
  root = SD.open("T.WAV");
  if (root) {    
    int c = 0;
    int n;
    while (root.available()) {
      switch(state){
        case HEADER_RIFF:
        wavRiff_t wavRiff;
        n = readRiff(root, &wavRiff);
        if(n == sizeof(wavRiff_t)){
          if(wavRiff.chunkID == CCCC('R', 'I', 'F', 'F') && wavRiff.format == CCCC('W', 'A', 'V', 'E')){
            state = HEADER_FMT;
            Serial.println("HEADER_RIFF");
          }
        }
        break;
        case HEADER_FMT:
        n = readProps(root, &wavProps);
        if(n == sizeof(wavProperties_t)){
          state = HEADER_DATA;
        }
        break;
        case HEADER_DATA:
        uint32_t chunkId, chunkSize;
        n = read4bytes(root, &chunkId);
        if(n == 4){
          if(chunkId == CCCC('d', 'a', 't', 'a')){
            Serial.println("HEADER_DATA");
          }
        }
        n = read4bytes(root, &chunkSize);
        if(n == 4){
          Serial.println("prepare data");
          state = DATA;
        }
        //initialize i2s with configurations above
        i2s_driver_install((i2s_port_t)i2s_num, &i2s_config, 0, NULL);
        i2s_set_pin((i2s_port_t)i2s_num, &pin_config);
        //set sample rates of i2s to sample rate of wav file
        i2s_set_sample_rates((i2s_port_t)i2s_num, wavProps.sampleRate); 
        break; 
        /* after processing wav file, it is time to process music data */
        case DATA:
        uint32_t data; 
        n = read4bytes(root, &data);
        i2s_write_sample_nb(data); 
        break;
      }
    }
    root.close();
  } else {
    Serial.println("error opening test.txt");
  }
  i2s_driver_uninstall((i2s_port_t)i2s_num); //stop & destroy i2s driver 
  Serial.println("done!");
}

void loop()
{
}
